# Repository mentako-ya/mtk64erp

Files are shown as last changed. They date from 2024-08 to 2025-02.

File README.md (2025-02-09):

[English](README.en.md)

# mtk64erp

親指操作トラックボールとロータリーエンコーダー付き自作キーボード

## オンラインストア
https://mentako-ya.myshopify.com

## News
[くま536](https://x.com/kuma534)様より[mtk64erpの紹介とファームウェアカスタマイズ](https://note.com/bright_boar9743/n/n3688c04d85e4)をご掲載いただきました

[しんぴのモノローグ](https://shinpi-gadget.com/)様にて[mtk64erpのレビュー](https://shinpi-gadget.com/mtk64erp-review/)をご掲載いただきました

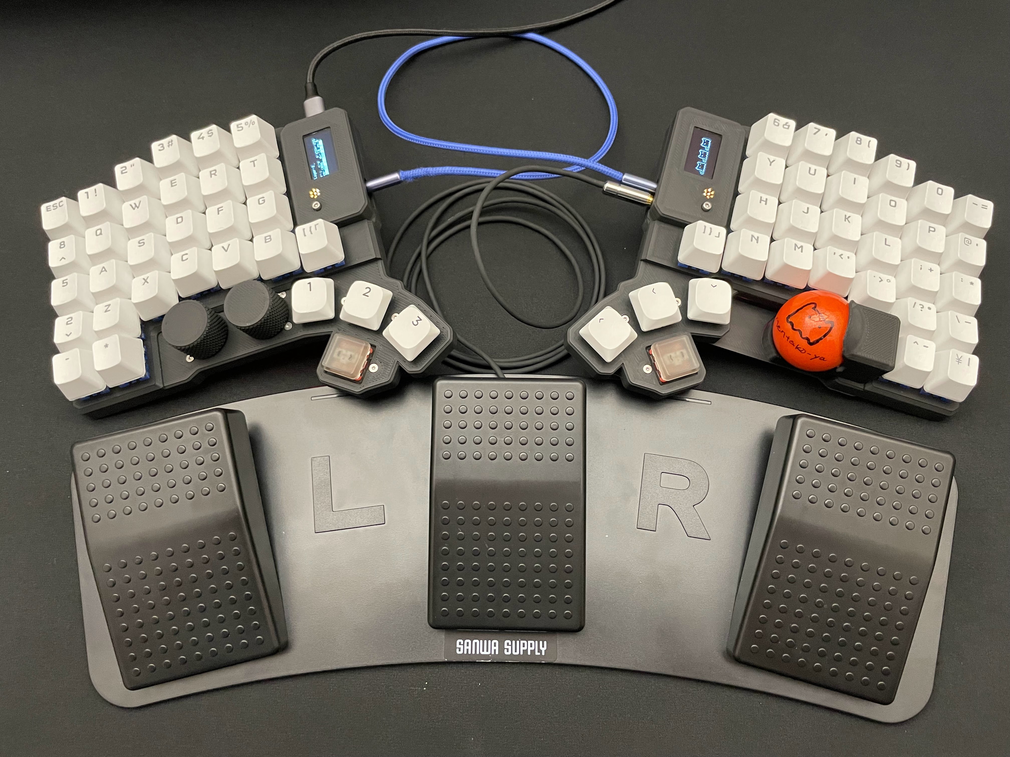
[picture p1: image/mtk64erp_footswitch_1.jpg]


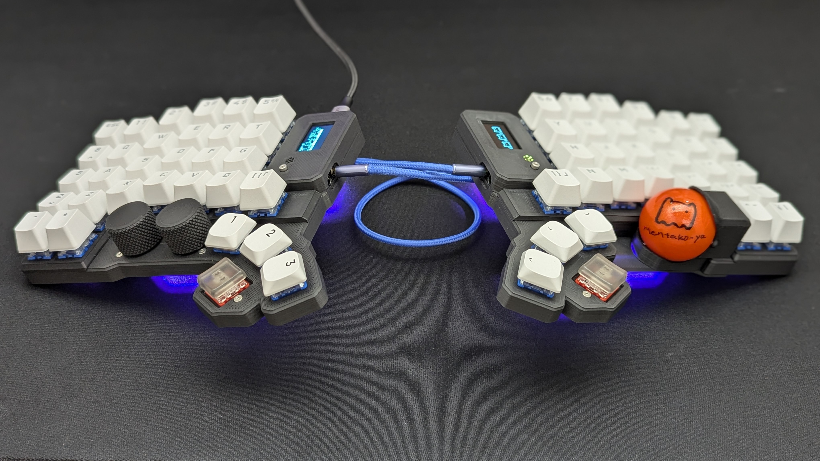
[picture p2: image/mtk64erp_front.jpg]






キーキャップMX互換:[CORSAIR PBT DOUBLE-SHOT 交換用カラーキーキャップセット - 日本語108キー, Arctic White - CH-9911040-JP](https://amzn.asia/d/1FShFiO)

キーキャップChocV2:[XVX ロープロファイル PBT キーキャップ](https://amzn.asia/d/7V1A6T4)

キーキャップChocV1:[Chocfox CFX keycap](https://chosfox.com/products/chocfox-cfx-choc-keycaps?bg_ref=3KtshOemT6)

トラックボール：[ぺリックス PERIPRO-303WH 34mm](https://amzn.asia/d/1paUF5C)

TRRSケーブル：https://shop.dailycraft.jp/products/trrs_cable_50_gloss

USB Type-cケーブル：https://amzn.asia/d/h8pfZIJ

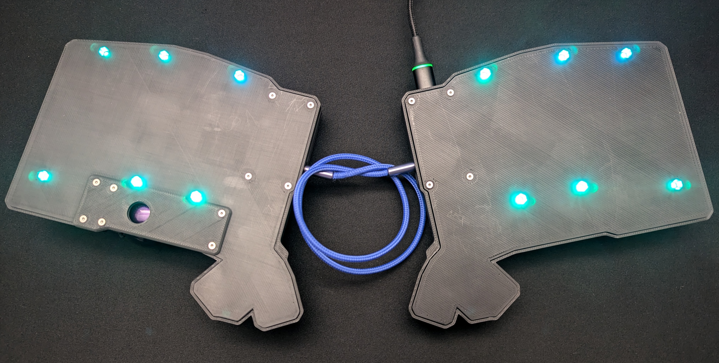
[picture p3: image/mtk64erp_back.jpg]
<br>
アンダーグローLED

<br>
追加の親指キースイッチは低くオフセットされている

<br>
OLED 128X64, レイヤー表示LED、リセットボタン

<br>
Alps alpine 低背エンコーダー、30クリック、プッシュスイッチ付き

<br>
PMW3389 トラックボールセンサーはキー押下時の干渉を避けるために低くオフセット

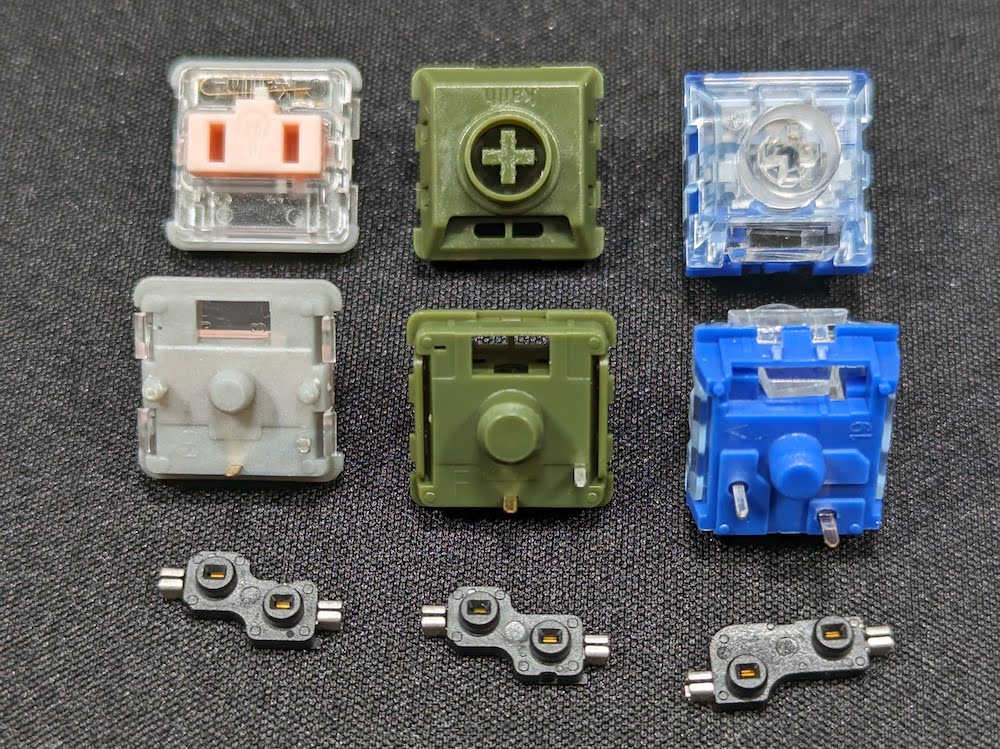
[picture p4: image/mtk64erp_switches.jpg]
<br>
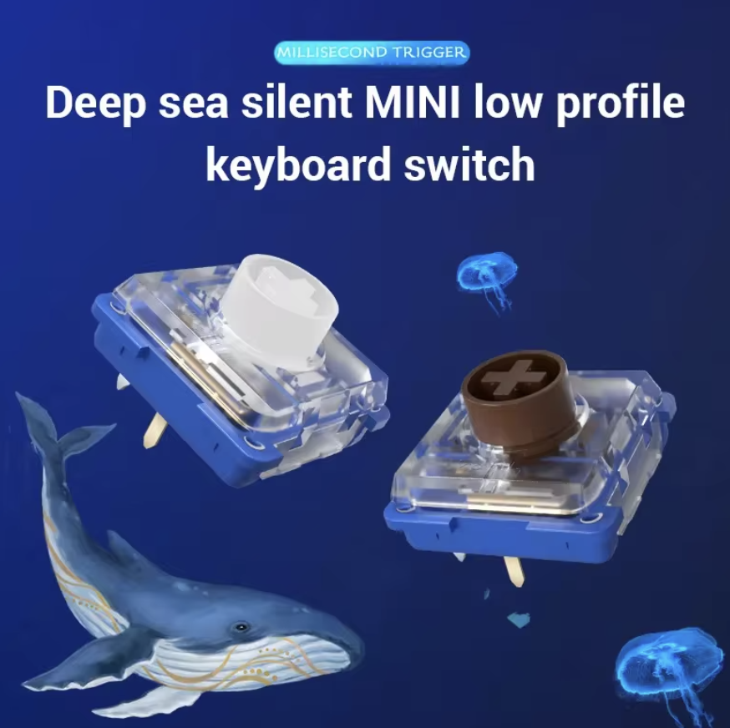
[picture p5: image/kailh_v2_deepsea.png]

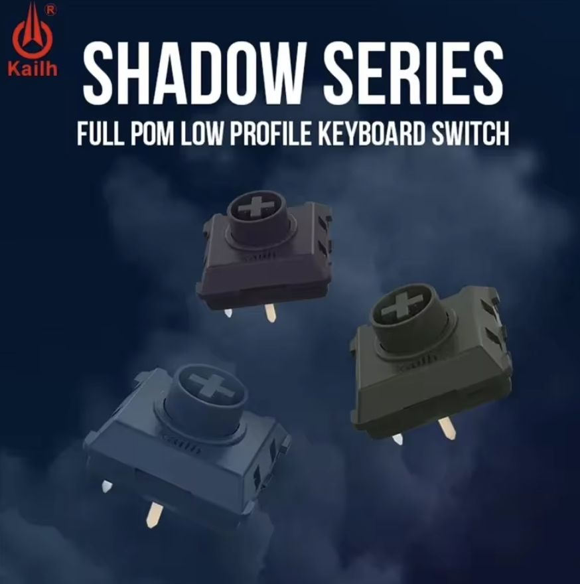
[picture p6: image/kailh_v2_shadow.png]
<br>
Chock V1/ [V2 (with out fixed pin model)](https://ja.aliexpress.com/item/1005007361067887.html) / MX互換キースイッチを全キーに取り付け可能

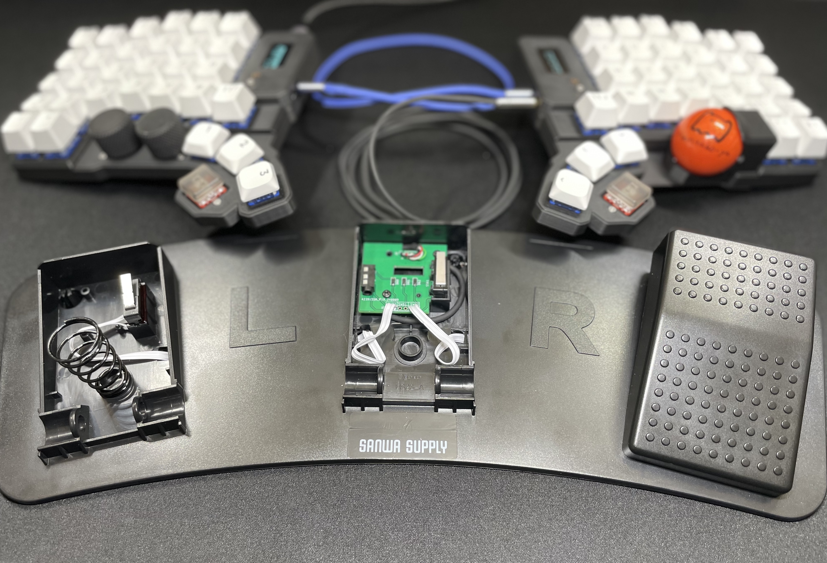
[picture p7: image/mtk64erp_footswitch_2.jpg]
<br>  

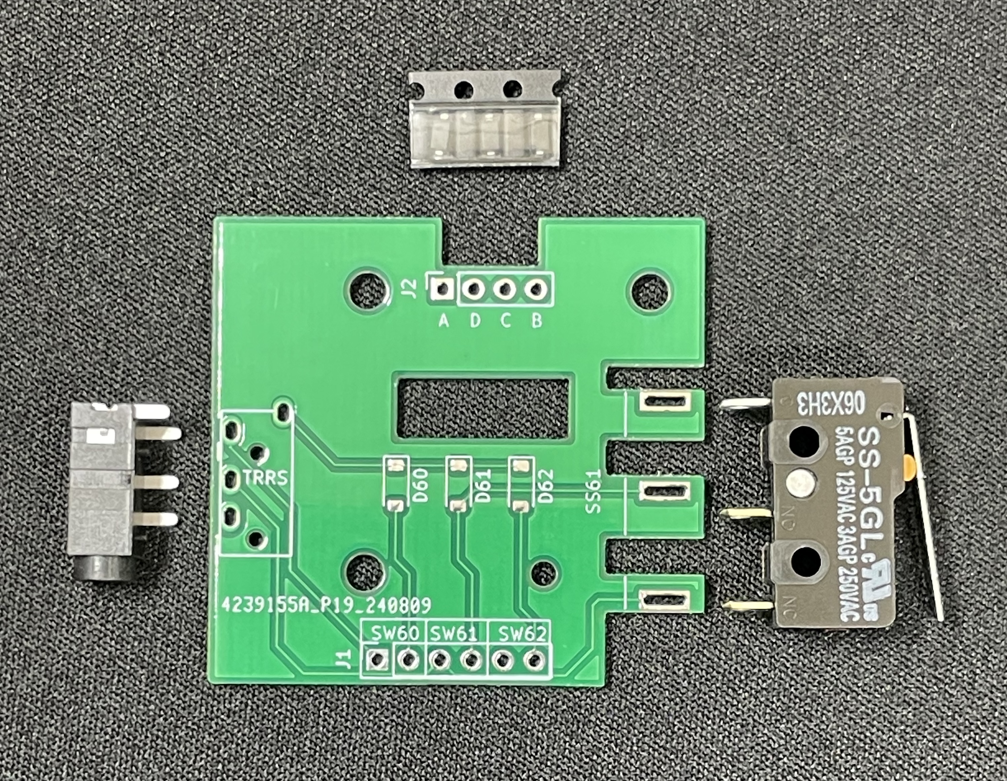
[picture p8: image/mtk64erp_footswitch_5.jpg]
<br>
フットスイッチ拡張キット<br>
[市販のUSBフットスイッチ](https://amzn.asia/d/h7wMR24)の基板と差し替えてmtk64erpに接続

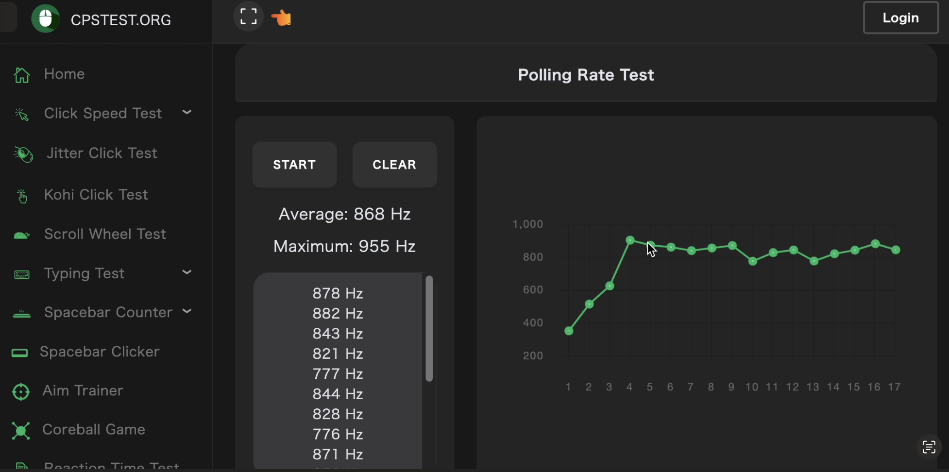
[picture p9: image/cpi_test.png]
<br>
新しい qmk_firmware と RP2040 MCU によるポーリング レートの向上

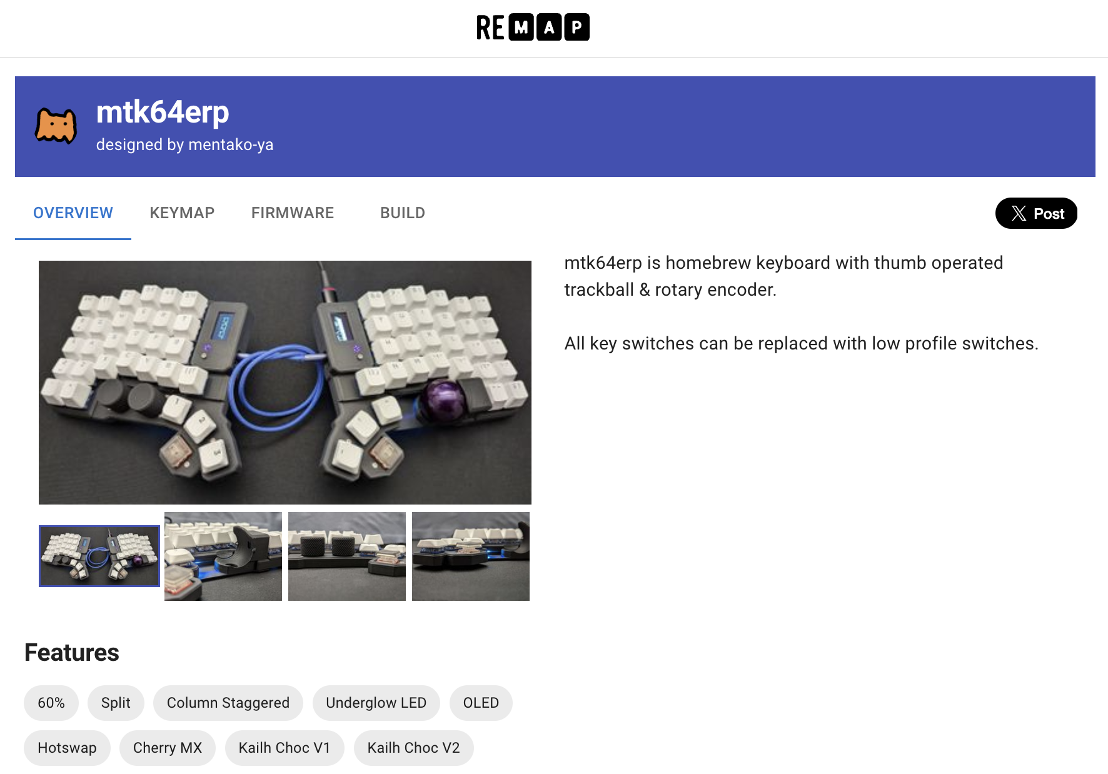
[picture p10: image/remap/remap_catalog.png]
<br>
[remap-keys.app](https://remap-keys.app/catalog/heEVSWdH2LCyxbQcQWwg) に登録 キーマップの変更、設定したキーマップの保存、共有、復元が可能

* サポートされているハードウェア: 

    MCU     : RP2040

    OLED    : SSD1306 128X64 

    Trackball sensor : PixArt PMW3389

    Encoder : Alps alpine EC12D

## ビルドムービー
https://www.youtube.com/playlist?list=PL_GJMtxZ-TgrWXYJNq9W5JQL1H6cIPeTs

## ファームウェア
[mtk_mtk64erp_via.uf2](firmware/mtk_mtk64erp_via.uf2)

### via.json
[mtk64erp_via.json](firmware/mtk64erp_via.json)

### ソースコード
https://github.com/mentako-ya/qmk_firmware/tree/master/keyboards/mtk/mtk64erp

Make example for this keyboard (after setting up your build environment):

    qmk compile -kb mtk/mtk64erp -km via

Flashing example for this keyboard:

    qmk flash -kb mtk/mtk64erp -km via

See the [build environment setup](https://docs.qmk.fm/#/getting_started_build_tools) and the [make instructions](https://docs.qmk.fm/#/getting_started_make_guide) for more information. 
Brand new to QMK? Start with our [Complete Newbs Guide](https://docs.qmk.fm/#/newbs).

### ブートローダー

2 つの方法でブートローダーに入る:

* **物理リセットボタン**: リセットボタンを短く2回押す
* **レイアウト内のキーコード**: `QK_BOOT` にマッピングされたキーを押す

## キーマッピング
https://remap-keys.app/configure を使用してキー マッピングを変更可能

 1. キーボードを接続する

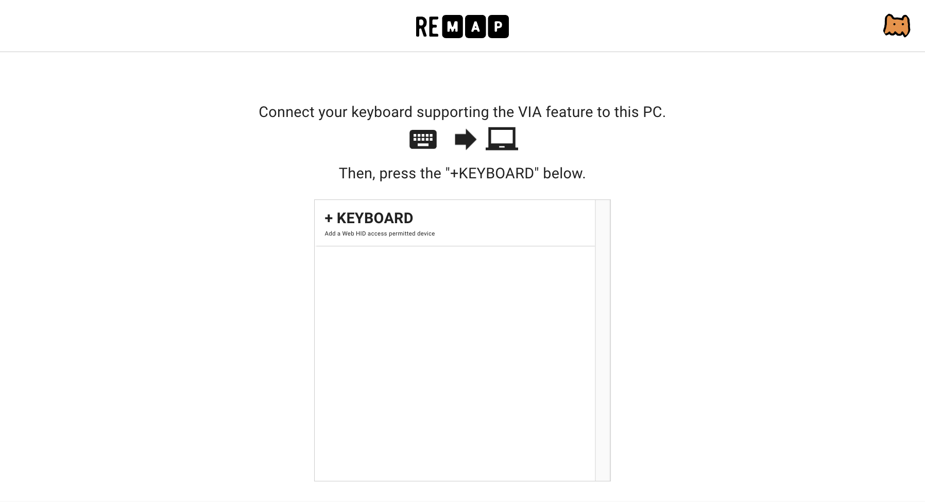
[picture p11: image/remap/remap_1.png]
    

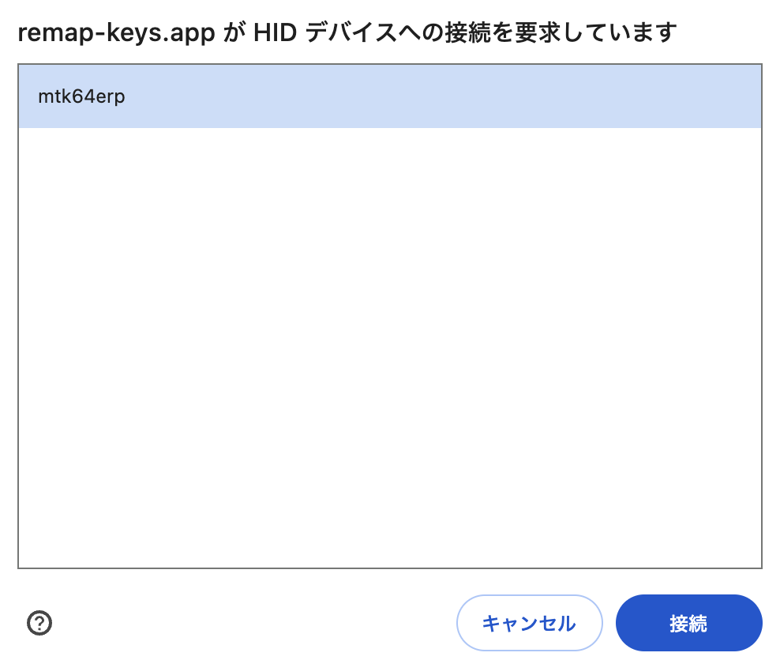
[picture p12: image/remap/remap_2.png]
    
 
 1. 任意のキーをレイヤー0~7にマッピング
* Layer 0       通常のキー

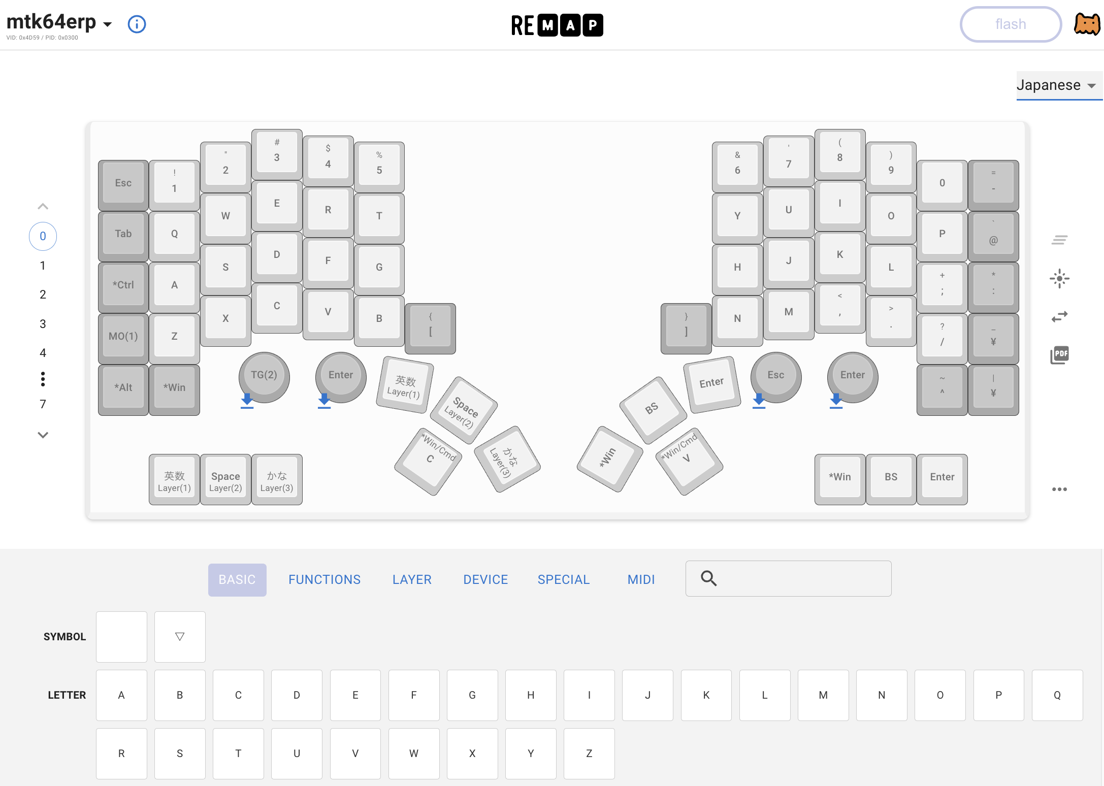
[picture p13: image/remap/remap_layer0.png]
    

* Layer 1       Shiftキーによる入力に相当

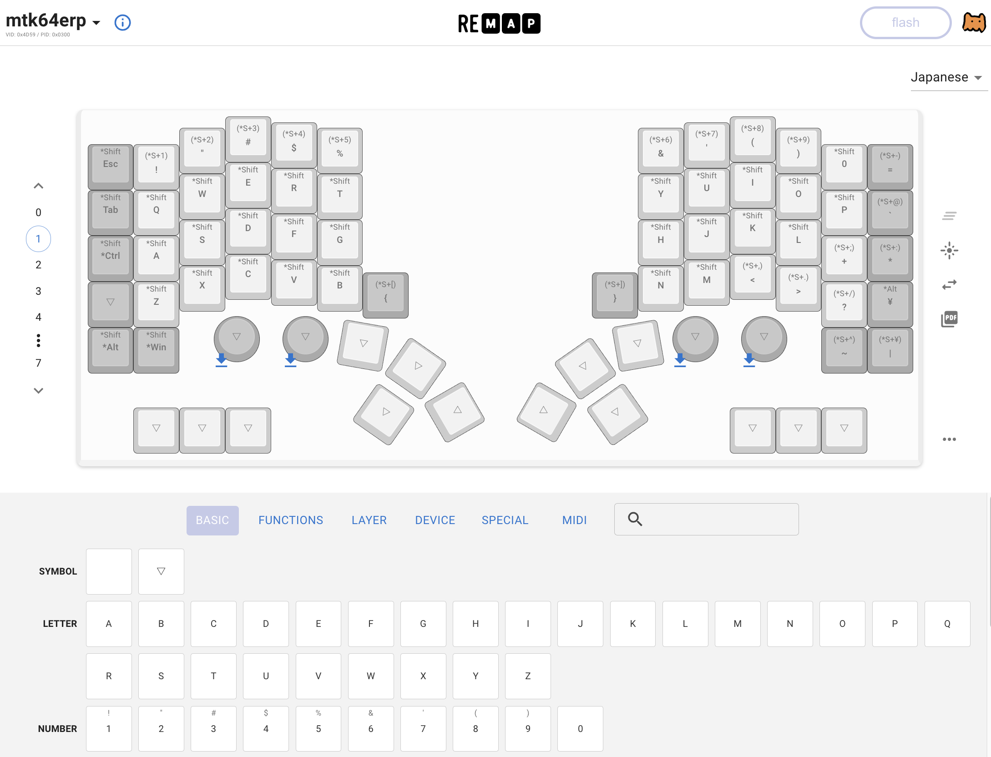
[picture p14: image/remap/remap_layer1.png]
    

* Layer 2       マウスボタン、カーソルキー

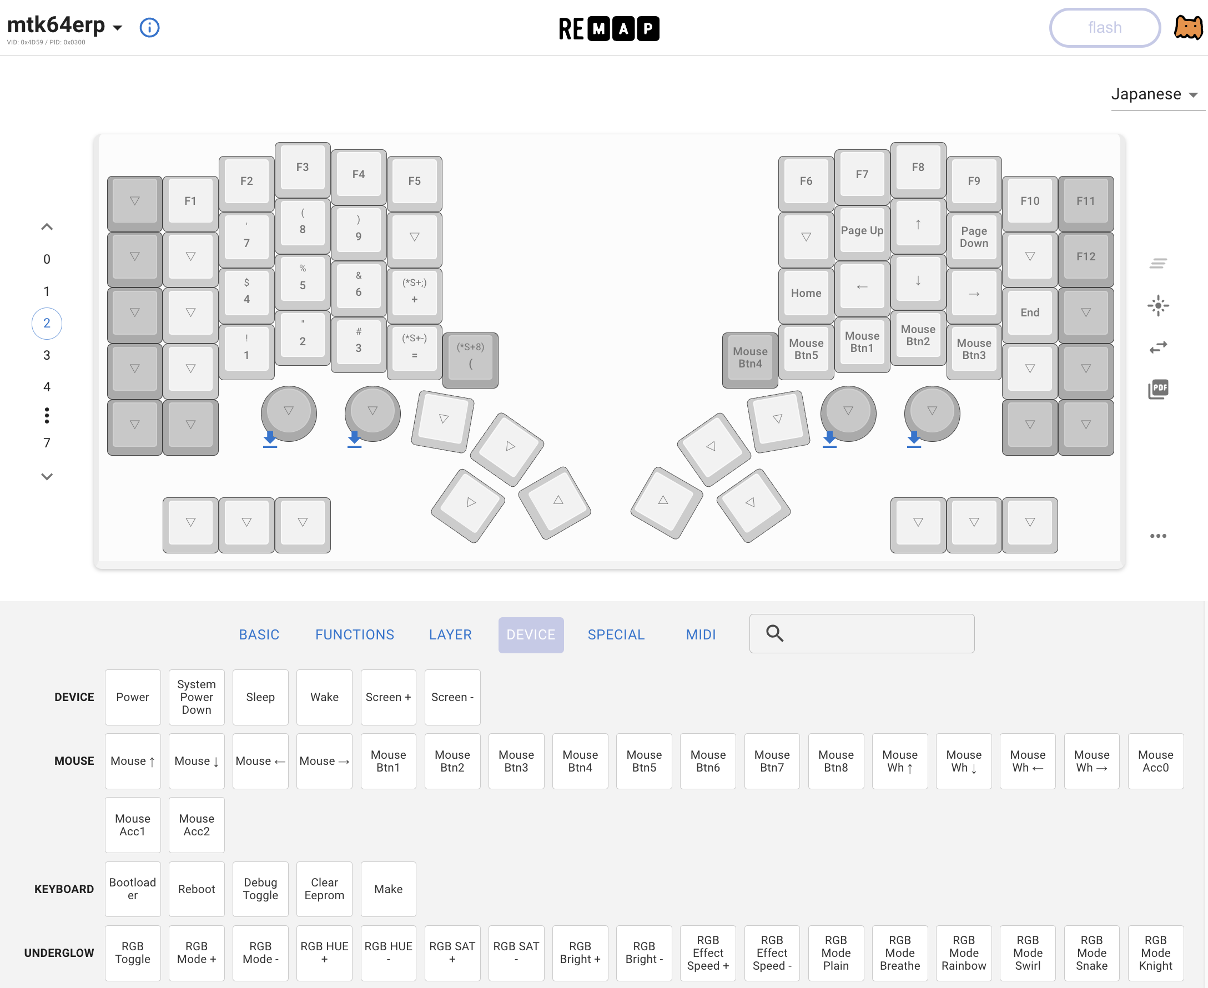
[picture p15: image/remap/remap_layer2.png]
    

* Layer 3       トラックボール設定 (カスタム キーコードを参照)、LED 設定、トラックボールをスクロール モードに切り替え

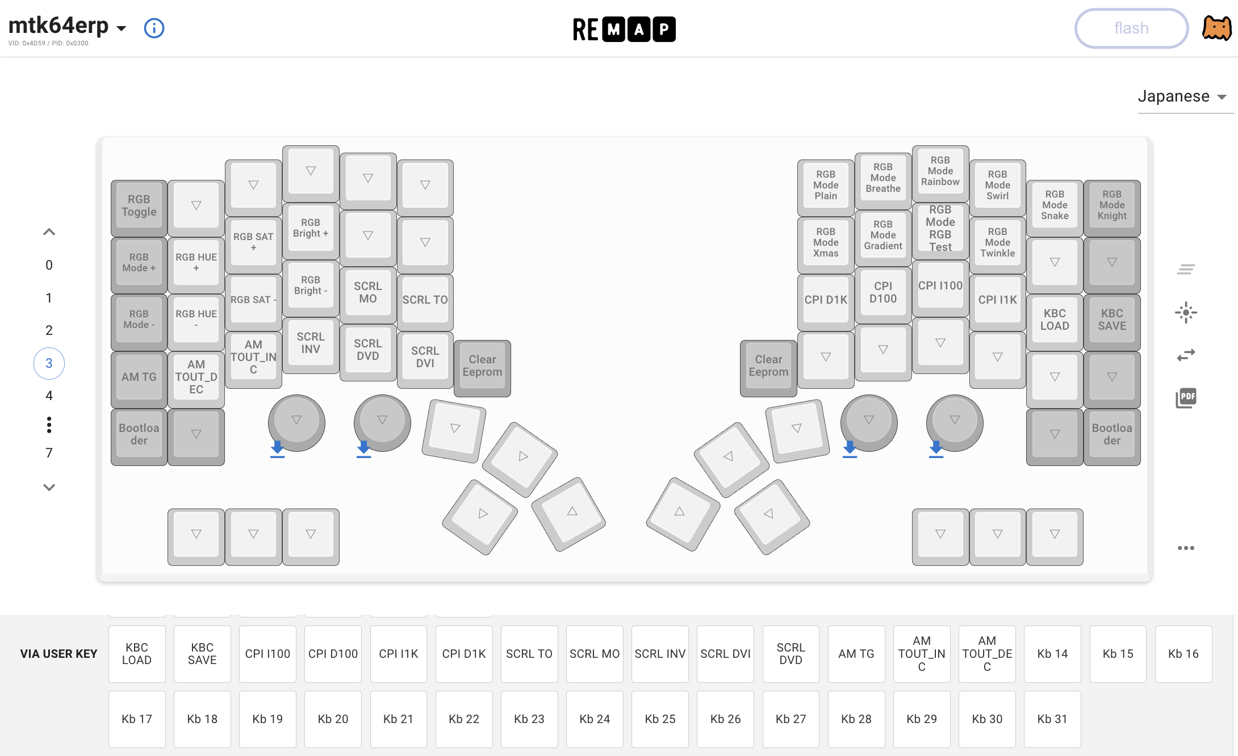
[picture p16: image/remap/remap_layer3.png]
    

* Layer 4..6    未使用、任意のキーコードを設定可能

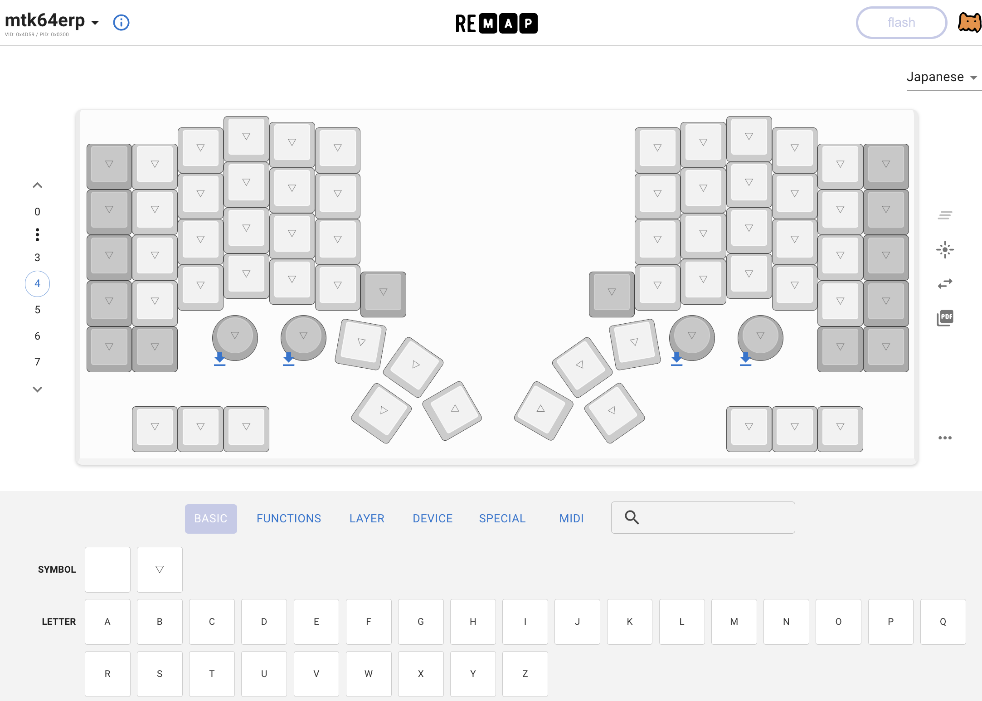
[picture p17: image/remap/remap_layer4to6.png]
    

* Layer 7       自動マウスレイヤー

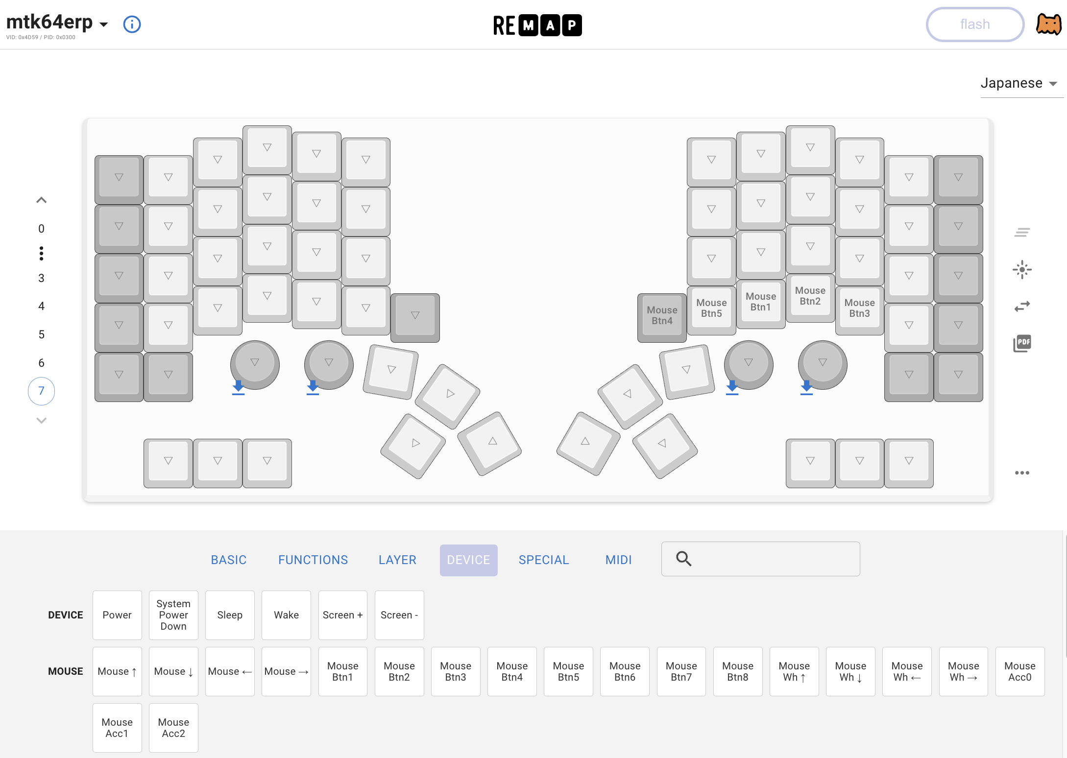
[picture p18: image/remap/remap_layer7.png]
    

### Cusom keycode
    KBC_LOAD,       // EEPROM からの設定ロード
    KBC_SAVE,       // EEPROM に設定を保存
    CPI_I100,       // CPI +100 CPI
    CPI_D100,       // CPI -100 CPI
    CPI_I1K,        // CPI +1000 CPI
    CPI_D1K,        // CPI -1000 CPI
    SCRL_TO,        // スクロールモードのオン/オフを切り替え
    SCRL_MO,        // 押下中スクロールモード
    SCRL_INV,       // スクロール方向を反転
    SCRL_DVI,       // スクロール分割値を増加
    SCRL_DVD,       // スクロール分割値を減少
    AM_TG,          // 自動マウスレイヤーのオン/オフを切り替え
    AM_TOUT_INC,    // 自動マウスレイヤーのタイムアウトを増加
    AM_TOUT_DEC,    // 自動マウスレイヤーのタイムアウトを減少

## ケースデータ
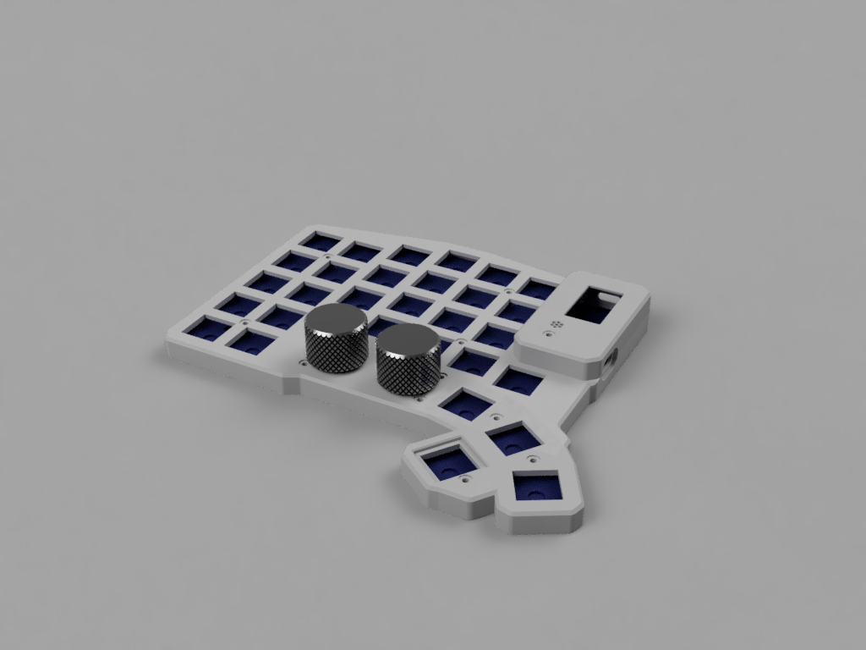
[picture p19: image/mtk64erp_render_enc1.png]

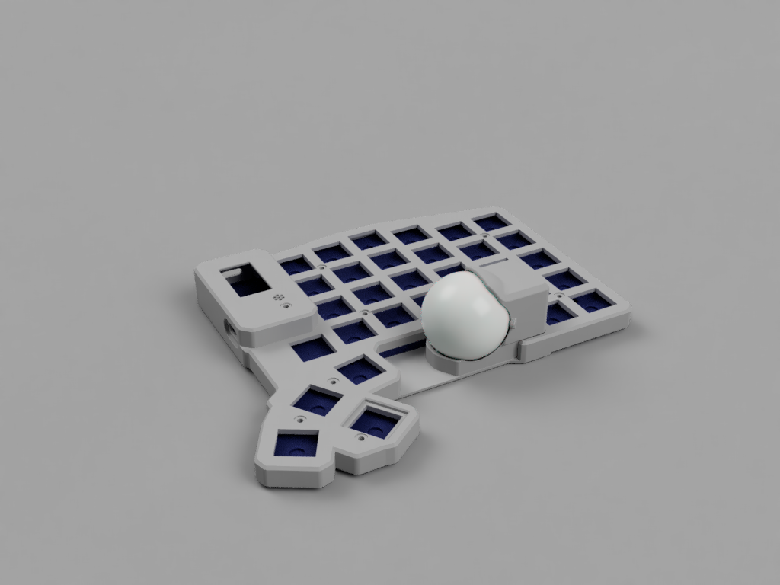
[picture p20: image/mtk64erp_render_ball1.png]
<br>
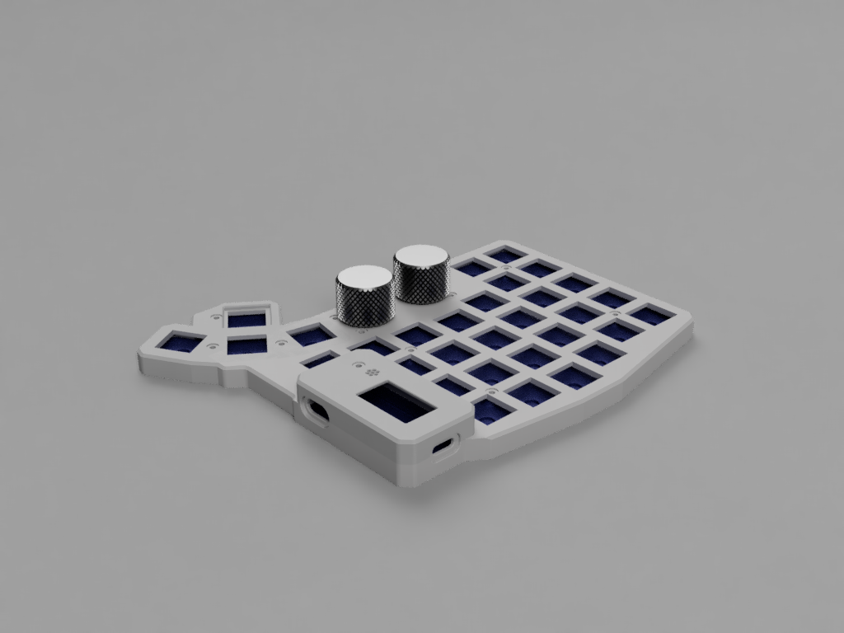
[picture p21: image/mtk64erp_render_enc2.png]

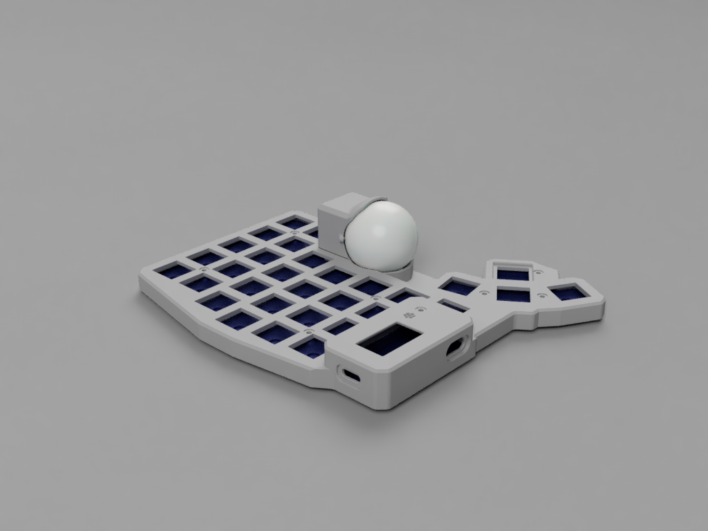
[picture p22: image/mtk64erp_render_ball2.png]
<br>

ケースデータのダウンロードは[こちら](casedata/mtk64erp_STL)

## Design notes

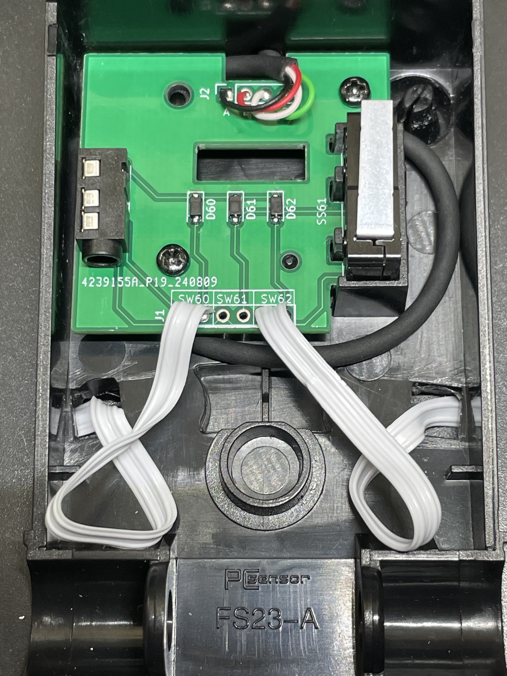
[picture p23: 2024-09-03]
image/mtk64erp_footswitch_3.jpg

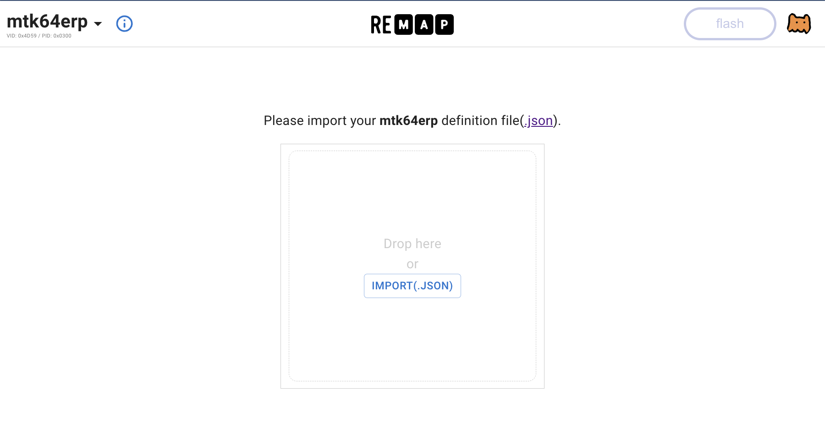
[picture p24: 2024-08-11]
image/remap/remap_3.png

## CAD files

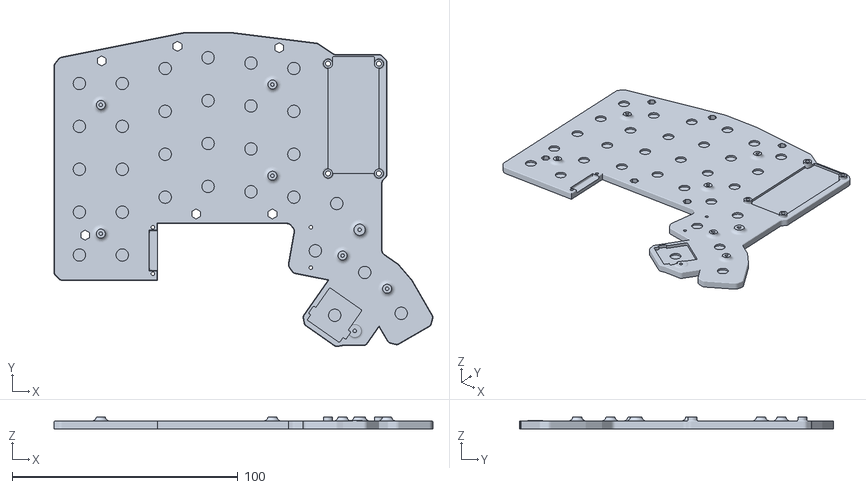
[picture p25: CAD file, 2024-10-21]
casedata/mtk64erp_STL/rev1/mtk64erp_Bottom_ball_LH.stl
167.9 x 139.2 x 5.40

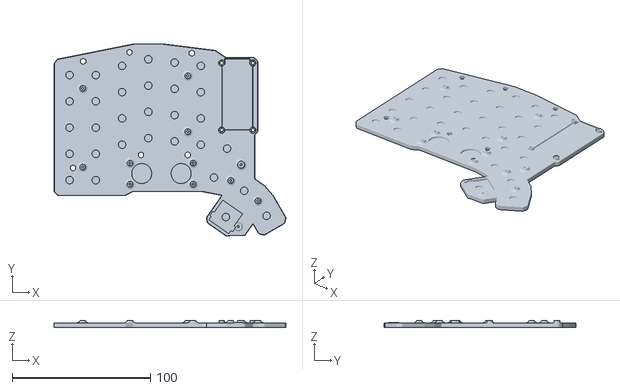
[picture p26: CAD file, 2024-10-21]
casedata/mtk64erp_STL/rev1/mtk64erp_Bottom_enc_LH.stl
167.9 x 139.2 x 5.40

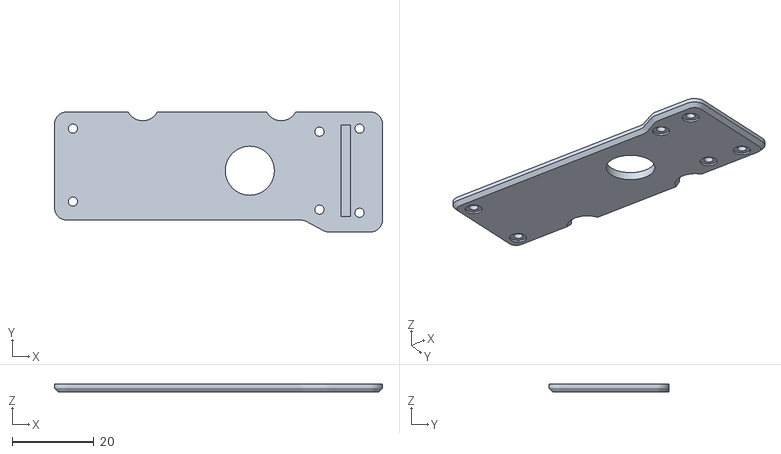
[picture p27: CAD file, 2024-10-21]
casedata/mtk64erp_STL/rev1/mtk64erp_BallCase_bottom_RH.stl
80.1 x 29.4 x 2.00

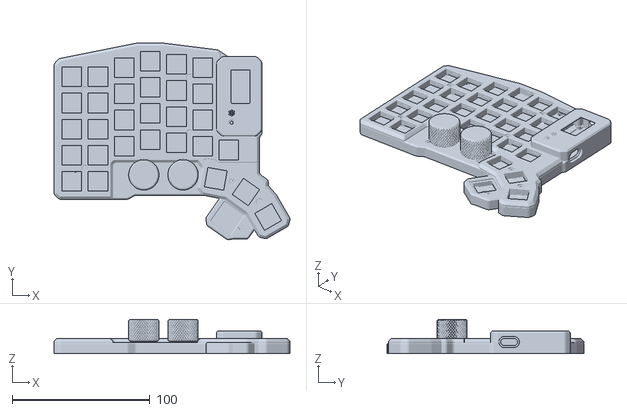
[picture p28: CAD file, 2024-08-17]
casedata/mtk64erp_STL/rev1/mtk64erp_EncoderSide.stl
171.4 x 142.8 x 25.0

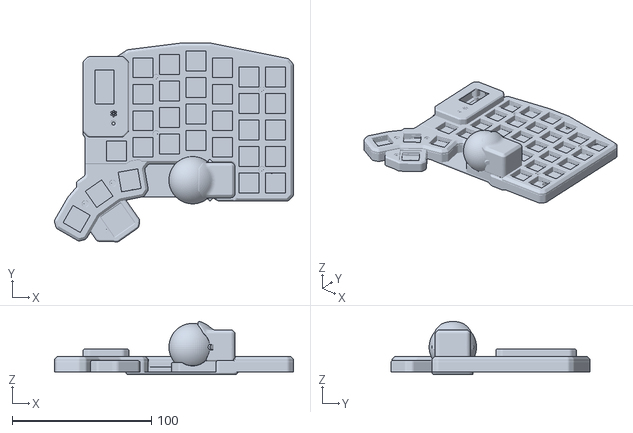
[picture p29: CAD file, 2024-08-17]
casedata/mtk64erp_STL/rev1/mtk64erp_TrackBallSide.stl
171.4 x 142.8 x 38.1

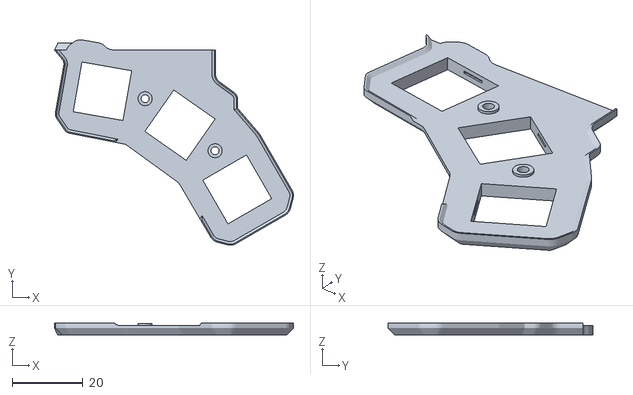
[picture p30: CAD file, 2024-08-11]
casedata/mtk64erp_STL/rev1/mtk64erp_top_plate_ball_thumb_RH.stl
67.4 x 58.0 x 3.50

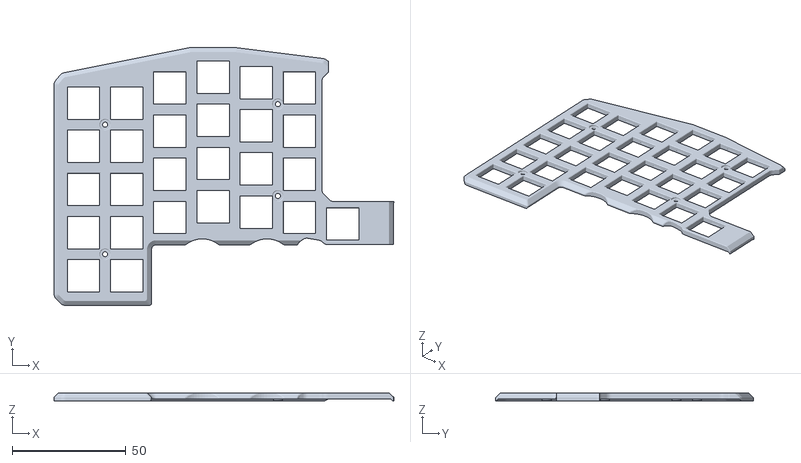
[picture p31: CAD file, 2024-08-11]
casedata/mtk64erp_STL/rev1/mtk64erp_top_plate_enc_body_LH.stl
149.6 x 113.4 x 3.62

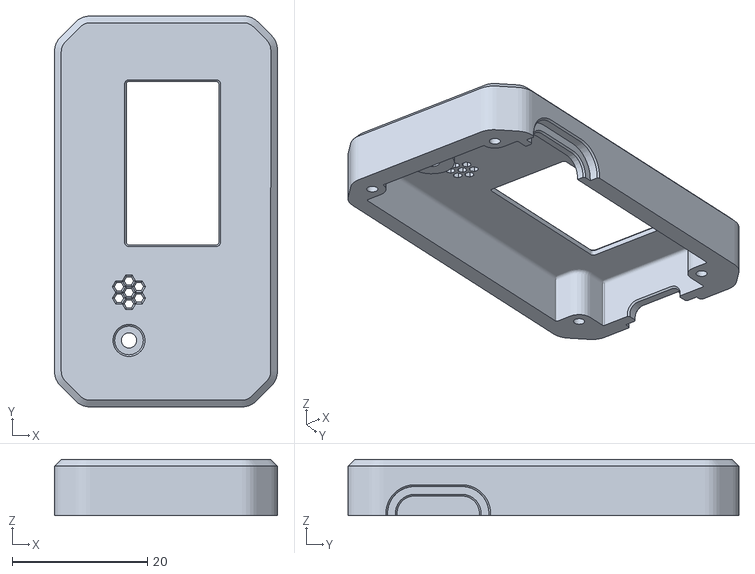
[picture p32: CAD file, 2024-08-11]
casedata/mtk64erp_STL/rev1/mtk64erp_Body_mcu_LH.stl
33.0 x 57.8 x 8.30

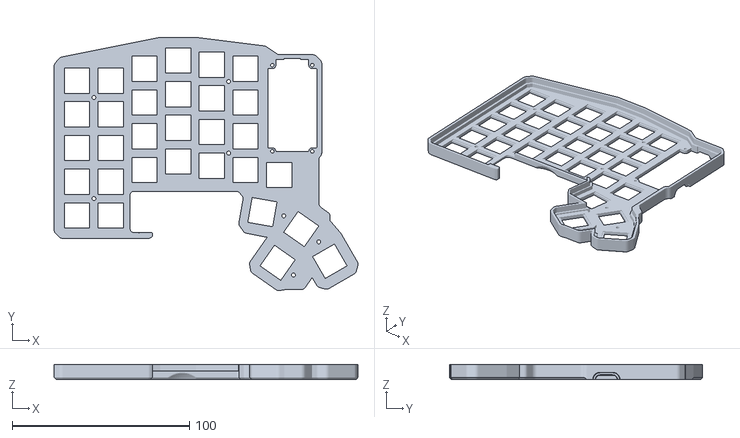
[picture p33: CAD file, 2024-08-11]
casedata/mtk64erp_STL/rev1/mtk64erp_Body_ball_RH.stl
171.4 x 142.8 x 8.20

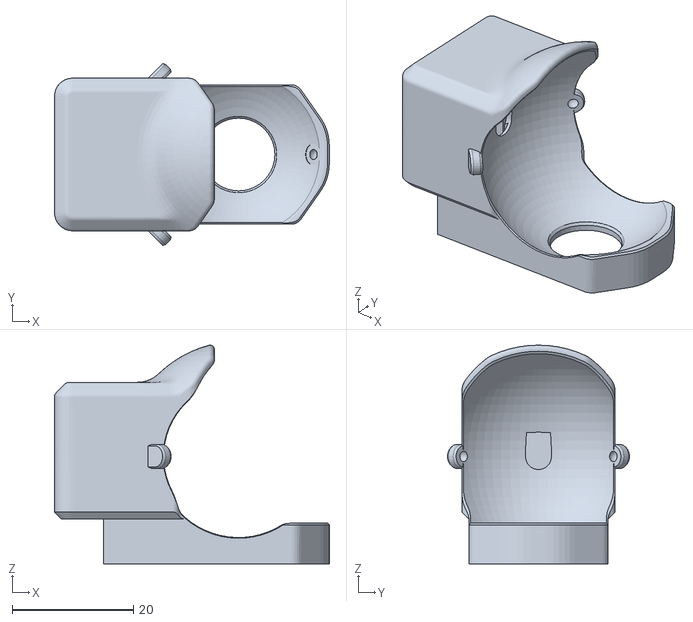
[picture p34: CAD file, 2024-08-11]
casedata/mtk64erp_STL/rev1/mtk64erp_BallCase_LH.stl
45.4 x 30.1 x 36.1

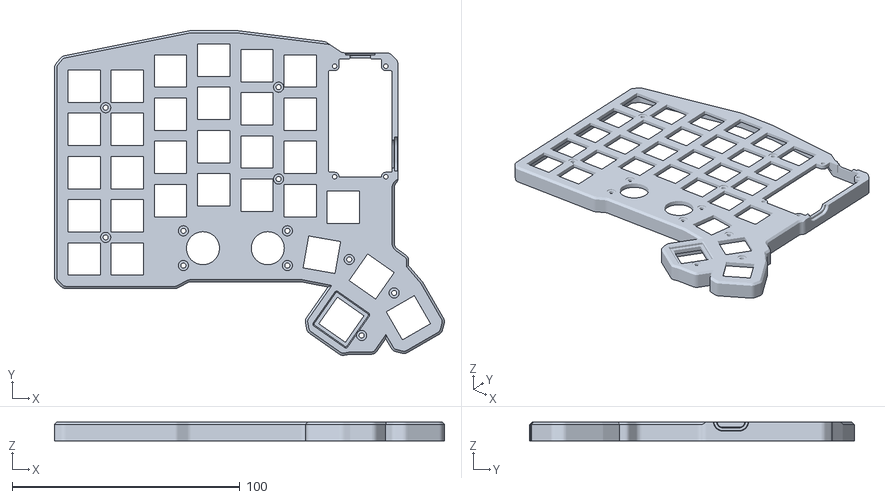
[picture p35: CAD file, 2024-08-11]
casedata/mtk64erp_STL/rev1/mtk64erp_Body_enc_LH.stl
171.4 x 142.8 x 8.20

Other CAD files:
casedata/mtk64erp_STL/rev1/mtk64erp_Bottom_ball_RH.stl
casedata/mtk64erp_STL/rev1/mtk64erp_top_plate_enc_thumb_LH.stl
casedata/mtk64erp_STL/rev1/mtk64erp_top_plate_ball_thumb_LH.stl
casedata/mtk64erp_STL/rev1/mtk64erp_top_plate_ball_body_RH.stl
casedata/mtk64erp_STL/rev1/mtk64erp_Body_mcu_RH.stl
casedata/mtk64erp_STL/rev1/mtk64erp_top_plate_ball_body_LH.stl
casedata/mtk64erp_STL/rev1/mtk64erp_BallCase_RH.stl
casedata/mtk64erp_STL/rev1/mtk64erp_Body_ball_LH.stl
casedata/mtk64erp_STL/rev1/mtk64erp_knob_19mm.stl

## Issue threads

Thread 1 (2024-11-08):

layerを選択しながら複数の操作ができない

masaru-suzuki, 2024-11-08:
hold時:layer(2)
tap時:Enter
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

layer(2)に移動して
*Shiftを押しながらcommand+pのボタンを押すと
command+pのボタンが反応しない問題が発生しています。
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

キースイッチの問題なのか設定の問題なのか判断がつかず、教えていただきたいです🙏

masaru-suzuki, 2024-11-08:
キースイッチの問題でした。失礼しました。

mentako-ya, 2024-11-09:
Shiftキー押下時の操作について、キースイッチの問題とのこと、ご報告ありがとうございました
お送りいただいた内容では、レイヤー０のShiftキー位置に「Shift」に設定されているので問題ないかと思いますが、デフォルトのキーマップをそのまま使用した場合、同様の事象が起こり得るケースがありますので、こちらに記載しておきます。

デフォルトのキーマップでは左のShiftキーの位置がShiftではなくMO1（レイヤー1に切り替え）になっています。
https://github.com/mentako-ya/mtk64erp/blob/main/image/remap/remap_layer0.png
レイヤー１にはShiftキー押下時相当のマッピングをセットしてあります。
（レイヤーの仕様方法の一例として設定したものです）
https://github.com/mentako-ya/mtk64erp/blob/main/image/remap/remap_layer1.png
キーキャップの種類（英語配列／日本語配列）とPCのキーボード配列設定が一致しない場合に記号の違いをマッピングで解消できるようにしています。
例えば英字キーキャップでShift+2は＠が印刷されていますが、PCの設定が日本語キーボードの場合、実際は”が入力されます。
このような場合にキーマップでMO1+2に＠をセットすることで、キーキャップと入力される記号の違いを解消できます。

ただし、Shiftキーとしての機能を全て置き換えできないので、このままでは、Shift+command+Pのような操作や、Shift+マウスクリックで複数範囲を選択といった操作ができなくなります。
キーキャップとPC側のキーボード設定が一致している場合は不要な設定ですので、左Shift位置のキーマップはShiftにしていただいた方が良いかと思います。

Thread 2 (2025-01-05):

PC立ち上げ後、一部のキー入力を検知するまでタイムラグが発生する

masaru-suzuki, 2025-01-05:
PC(mac mini m2 pro)を立ち上げた後、20~40分くらい経たないと一部のキーの入力をPCが検知できない問題が発生しております。
特定の列のみ反応がないので、基盤の不具合が起こっているのかもしれないと考えています。
何か検証する術があれば教えていただきたいです！🙏

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

masaru-suzuki, 2025-01-20:
ハンダ不良はなさそうでした。
また、GP21にとcol6の金属部分をテスターで導通テストを行いましたが、そこも問題なさそうです。
自動ハンダ吸い取り機などはないので、修理をお願いしたいです。

---

最初から発生していたかどうかは正直覚えていないです....
時間をおけば解決していたので、購入当時はあまり気にしていなかったような気もしますが、問題なく入力されていたような気もしています。

mentako-ya, 2025-01-21:
修理についてご連絡させていただきますので、mentakoya@gmail.comまでご連絡ください。

mentako-ya, 2025-01-21:
GP21の故障の要因として、フットスイッチ用のジャックに通電状態のまま左右間接続のTRSケーブルを差し込むと故障します。
左右間接続のTRSには電源端子があるのでUSBケーブルを挿して通電状態のまま抜き差しをするとMCUが故障します。
左右のTRSを通電状態で抜き差しすると、IOの故障により左右間通信ができなくなります。
フットスイッチ用のジャックと反対側のTRSを繋いだ場合、フットスイッチ用ジャックに結線されているキースイッチの行、列スキャンのIOが損傷します。（GPIO21はフットスイッチの端子に接続されています）

TRSケーブルの抜き差しはUSBケーブルを抜いてから行ってください。
https://salicylic-acid3.hatenablog.com/entry/split-keeb-notes

masaru-suzuki, 2025-01-26:
> フットスイッチ用のジャックに通電状態のまま左右間接続のTRSケーブルを差し込むと故障します。

ありがとうございます。
キーボードの反応が悪い時に、通電状態で左右のキーボードを繋ぐ端子を抜き差ししていたことがあったので、それが原因かもしれないです....

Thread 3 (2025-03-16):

左側のProMicroが認識されなくなった

fumisone, 2025-03-16:
左側にケーブルを接続して、通電を確認してから操作をしようとしたところ操作ができず確認したところOLEDが消えていました。
それ以降、左側にケーブルを接続してもPCから全く認識されません。
右側にケーブルを接続すると左右とも問題なく利用可能でした。
原因としてありそうなことや調査方法、修正方法等わかればご教示いただけないでしょうか。

mentako-ya, 2025-03-17:
左右接続して右手側にUSB接続すると正常にどうさせうるとのことですので、左手側のUSBの不具合が疑われます。

以下の手順で問題箇所の特定、問題の切り分けをしてください。
OK/NGを全て記録して**問題のない箇所**を確定してください。
問題があるところだけを確認しても、正しく切り分けできません。

1. USBケーブル、TRSケーブル、PCを別の良品に交換してテスト
（以下、全ての切り分け手順で複数のケーブル、PCを使用して確認）

2. 左手単独、右手単独でUSB接続してRemapに接続し、mtk64として認識されるか確認
mtk64として認識されない場合、USBケーブル、PCを良品に交換して確認
mtk64して認識された場合、Remapでテストマトリクスモードで全キーの動作確認

3.左手単独で問題なければ、USBケーブルを外して左右間をTRS接続して、再確認
* TRS接続して左側USB接続して左右とも正しく動作しない
* TRS接続して右側USB接続して左右とも正しく動作しない
* TRS接続して左側USB接続して左側が正しく動作しない
* TRS接続して右側USB接続して右側が正しく動作しない
* TRS接続して左側USB接続して左側が正しく動作、右側が正しく動作しない
* TRS接続して右側USB接続して右側が正しく動作、左側が正しく動作しない
上記のどのパターンに当てはまるのか全パターンを確認、
どのパターンに当てはまるのか、どのパターンは問題ないのかによって調査箇所を絞り込み
左右間接続のTRSケーブル、端子不具合（右側、左側いずれかもしくは両方）
　→端子にTRSケーブルを接続してテスターで端子側とケーブルの末端で同通確認　４極全て通電しているか、ショートしていないか、逆に刺しても同じか、別のケーブルに変えても同じか
左右間通信のGPIO故障（右側、左側いずれかもしくは両方）
　→MCUの故障

3. 左右単独でUSBケーブルを良品にしても改善しなければ、PCにUSB接続した状態でリセットスイッチをダブルクリック
PC側からUSBドライブとして認識されたらファームウェアを上書き、FEPROMリセットを実行
再度左右単独でUSB接続してRemapに接続し、mtk64として認識されるか確認

4. PCからUSBドライブとして認識されない場合、通電しているか確認
PCにUSB接続した状態でリセットスイッチをダブルクリックしてProMicroと本体基盤の隙間からProMicroの表面に実装されたLEDが点灯するかを確認
→点灯していなければUSB端子の破損
→点灯している場合MCUの故障

MCUの故障は修理できないので、Promicroごと交換になります。
はんだ吸い取り機を使用して、全てのピンのハンダを除去する必要がありますが、手動のはんだ吸い取り機ではMCUの取り外しは困難です。

fumisone, 2025-03-18:
ご返信ありがとうございます。
確認結果は以下の通りです。
1．全パターンで右手のみ認識
2．全パターンで右手のみ認識
3．USBデバイスとして認識されず
4．こちらはMCUカバーを外して点灯していないことを確認、確認方法に問題があればご教示ください。

TRRSケーブルのUSB接続中に抜き差しや違う場所への接続はしていません。

念の為メールを送信したいのですが、メールアドレスはどこかに記載あるでしょうか。

mentako-ya, 2025-03-19:
3のところが番号被っていました
右側にUSB接続した際に左側が生きているのかわかりませんでしたがおそらく左のUSB端子破損だと思います。
メールアドレスはmentakoya@gmail.comです。

fumisone, 2025-03-20:
すみません、わかりにくかったです。
最初にお伝えした通り右手に接続した際は、問題なく左手も操作可能でした。
先ほどメールを送信しましたのでご確認ください。

fumisone, 2025-03-30:
ご対応のほどありがとうございました。

クローズいたします。

Closed 2025-03-30.

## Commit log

2024-08-17 readme 更新
    [mtk64erp_EncoderSide.stl, mtk64erp_TrackBallSide.stl]
2024-09-03 Footswitch追加
2024-10-21 Update case data.
    [mtk64erp_BallCase_bottom_RH.stl, mtk64erp_Bottom_ball_LH.stl, mtk64erp_Bottom_ball_RH.stl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]
